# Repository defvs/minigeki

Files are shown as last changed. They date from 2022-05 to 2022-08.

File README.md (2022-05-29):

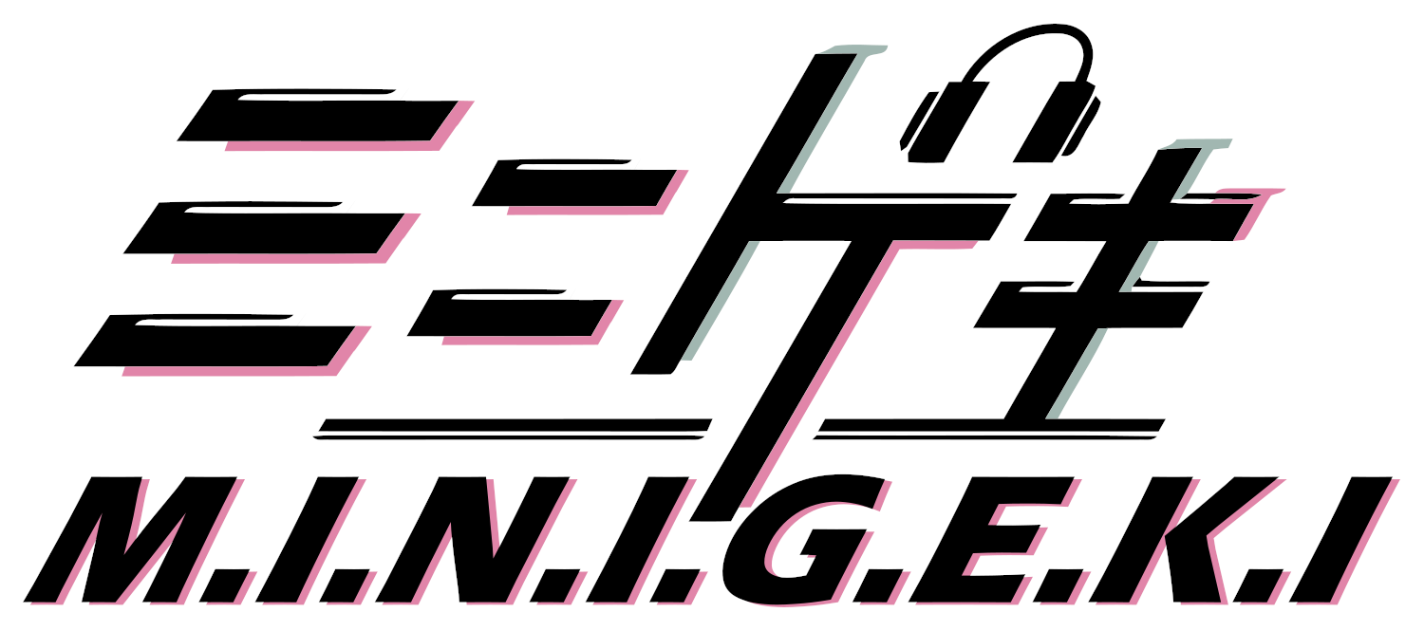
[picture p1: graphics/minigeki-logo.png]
Minigeki Logo

# M.I.N.I.G.E.K.I : a portable ONGEKI controller

A portable implementation of an ONGEKI controller, with all necessary buttons, two macros, RGB LED support, USB-C.

## Hardware setup

- Raspberry RP2040 microcontroller
- 10 hotswappable Cherry MX switches (2x Start, 2x Wall, 2x R+G+B), 2 Macro switches
- 10 RGB daisy-chained WS2812-compatible LEDs (Under every switch except Start, and two under the board)
- USB Type-C connector for both data and power. 

## Software capabilities

- HID Gamepad mode or HID Mouse/Keyboard mode
    - Switchable on boot
- Software addressable RGB via HID
- Auto-rollback to static RGB LEDs if no HID is detected
    - LED can be disabled on boot
- High polling rate
- Switch debouncing
- 8-bit slider position

## Based on / sources

- This project's code is based on SpeedyPotato's [Pico-Game-Controller](https://github.com/speedypotato/Pico-Game-Controller)
    - It also includes sources from Raspberry Pi's [pico-examples](https://github.com/raspberrypi/pico-examples)
- This project's PCB is based on Raspberry Pi's [RP2040-Minimal design](https://datasheets.raspberrypi.com/rp2040/Minimal-KiCAD.zip)

## License and Open Source licensing

minigeki is under GPLv3 in compliance with the usage of existing GPLv3 code. License information can be found in the LICENSE file.

A list of open source components and their licenses can be found in the LICENSING file.

## Extra credit and thank you

- CrazyRedMachine
- megumi_akasaka
- SpeedyPotato

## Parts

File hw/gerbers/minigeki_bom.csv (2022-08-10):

Item | Qty | Reference(s) | Value | LibPart | Footprint | Datasheet | Description | Load Capacitance | MPN | Package
1 | 2 | C1, C4 | 10u | Device:C | Capacitor_SMD:C_0805_2012Metric | ~ |  |  |  | 0805
2 | 2 | C2, C3 | 27p | Device:C | Capacitor_SMD:C_0402_1005Metric | ~ |  |  |  | 0402
3 | 20 | C5, C6, C7, C9, C11, C12, C13, C14, C15, C16, C17, C18, C19, C20, C21, C22, C23, C24, C25, C26 | 100n | Device:C | Capacitor_SMD:C_0402_1005Metric | ~ |  |  |  | 0402
4 | 2 | C8, C10 | 1u | Device:C | Capacitor_SMD:C_0402_1005Metric | ~ |  |  |  | 0402
5 | 10 | D1, D2, D3, D4, D5, D6, D7, D8, D9, D10 | SK6812MINI | LED:SK6812MINI | LED_SMD:LED_SK6812MINI_PLCC4_3.5x3.5mm_P1.75mm | https://cdn-shop.adafruit.com/product-files/2686/SK6812MINI_REV.01-1-2.pdf | SK6812MINI |  | SK6812MINI | PLCC4_3.5x3.5mm_P1.75mm
6 | 1 | J1 | USB_C_Receptacle_USB2.0 | Connector:USB_C_Receptacle_USB2.0 | Connector_USB:USB_C_Receptacle_XKB_U262-16XN-4BVC11 | https://www.usb.org/sites/default/files/documents/usb_type-c.zip | U262-161N-4BVC11 |  | U262-161N-4BVC11 | U262-161N-4BVC11
8 | 2 | R1, R5 | 1k | Device:R | Capacitor_SMD:C_0402_1005Metric | ~ |  |  |  | 0402
9 | 1 | R2 | DNF | Device:R | Capacitor_SMD:C_0402_1005Metric | ~ |  |  |  | 0402
10 | 2 | R3, R4 | 27 | Device:R | Capacitor_SMD:C_0402_1005Metric | ~ |  |  |  | 0402
11 | 2 | R6, R7 | 5.11k | Device:R | Resistor_SMD:R_0402_1005Metric | ~ |  |  |  | 0402
12 | 1 | RV1 | PTA4543-2015DPB103 | Device:R_Potentiometer | PTAXX33:PTAXX43 | ~ | PTA4543-2015DPB103 |  | PTA4543-2015DPB103
23 | 1 | U1 | NCP1117-3.3_SOT223 | Regulator_Linear:NCP1117-3.3_SOT223 | Package_TO_SOT_SMD:SOT-223-3_TabPin2 | http://www.onsemi.com/pub_link/Collateral/NCP1117-D.PDF | NCP1117ST33T3G |  | NCP1117ST33T3G | SOT223-3
24 | 1 | U2 | W25Q128JVS | Memory_Flash:W25Q128JVS | Package_SO:SOIC-8_5.23x5.23mm_P1.27mm | http://www.winbond.com/resource-files/w25q128jv_dtr%20revc%2003272018%20plus.pdf | W25Q128JVS |  | W25Q128JVS | SOIC-8_5.23x5.23mm_P1.27mm
25 | 1 | U3 | RP2040 | MCU_RaspberryPi_RP2040:RP2040 | RP2040_minimal:RP2040-QFN-56 |  | RP2040 |  | RP2040 | QFN-56
26 | 1 | Y1 | Q22FA23V0041800 | Device:Crystal_GND24 | Crystal:Crystal_SMD_3225-4Pin_3.2x2.5mm | https://datasheet.lcsc.com/lcsc/1811051112_Seiko-Epson-Q22FA23V0041800_C91749.pdf | Q22FA23V0041800 | 18p | Q22FA23V0041800 | MD_3225-4Pin_3.2x2.5mm

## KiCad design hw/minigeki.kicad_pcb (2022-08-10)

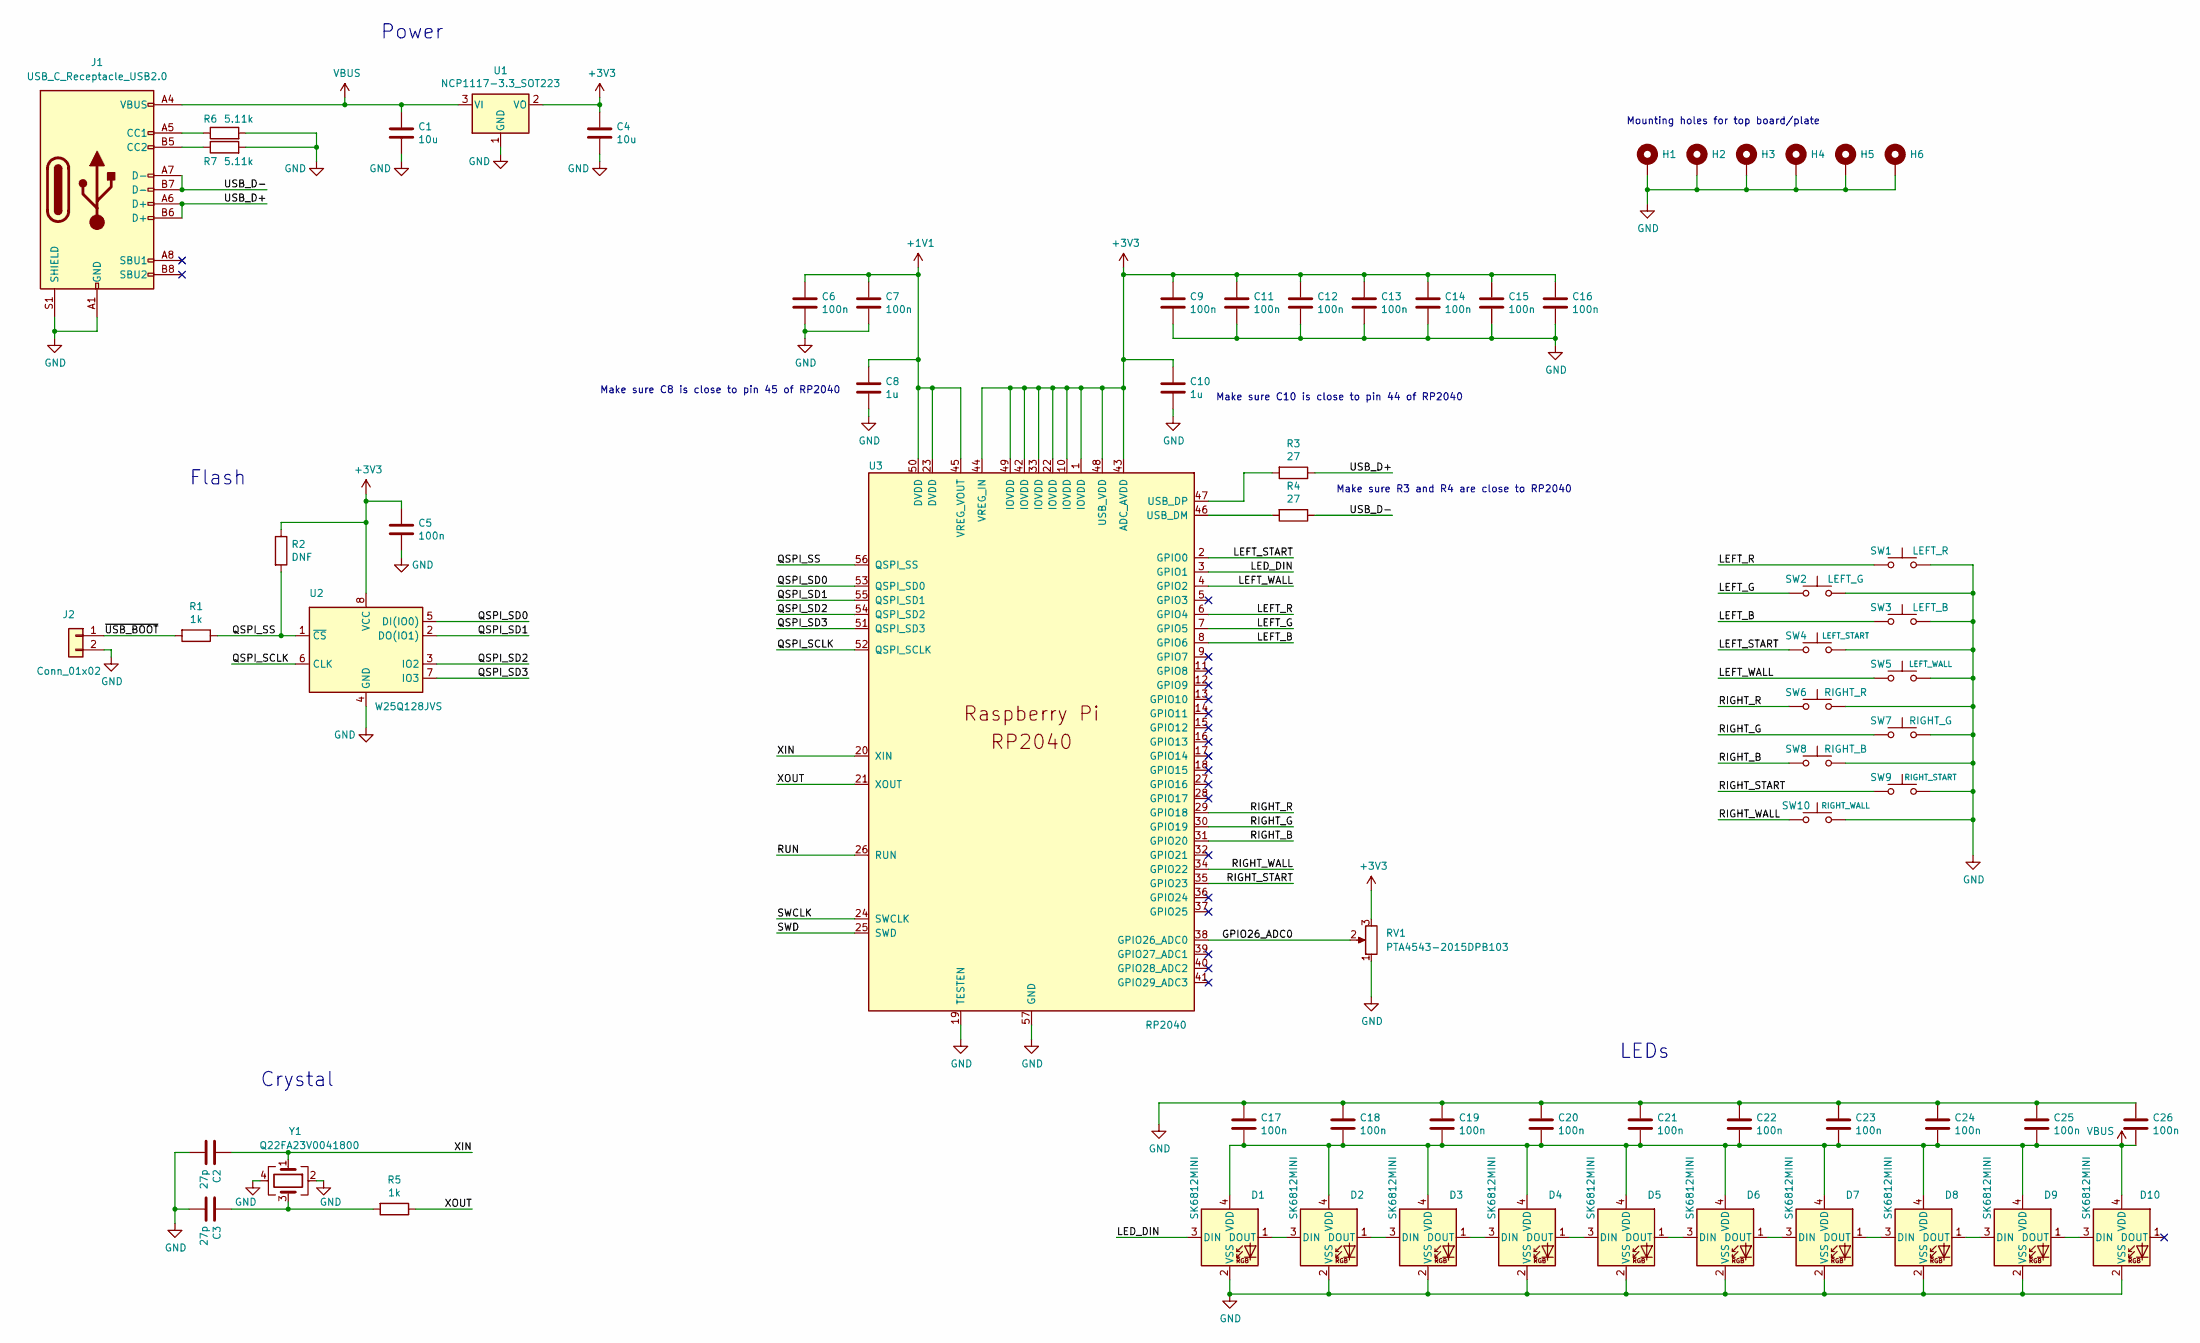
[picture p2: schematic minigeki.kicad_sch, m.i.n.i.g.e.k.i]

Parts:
C1, C4: 10u; C_0805_2012Metric
C2, C3: 27p; C_0402_1005Metric
C5, C6, C7, C9, C11, C12, C13, C14, C15, C16, C17, C18, C19, C20, C21, C22, C23, C24, C25, C26: 100n; C_0402_1005Metric
C8, C10: 1u; C_0402_1005Metric
D1, D2, D3, D4, D5, D6, D7, D8, D9, D10: SK6812MINI; LED_SK6812MINI_PLCC4_3.5x3.5mm_P1.75mm; MPN SK6812MINI
H1, H2, H3, H4, H5, H6: MountingHole_Pad; MountingHole_2.2mm_M2_Pad_TopOnly
J1: USB_C_Receptacle_USB2.0; USB_C_Receptacle_XKB_U262-16XN-4BVC11; MPN U262-161N-4BVC11
J2: Conn_01x02; PinHeader_1x02_P2.54mm_Vertical
R1, R5: 1k; C_0402_1005Metric
R2: DNF; C_0402_1005Metric
R3, R4: 27; C_0402_1005Metric
R6, R7: 5.11k; R_0402_1005Metric
RV1: PTA4543-2015DPB103; PTAXX43; MPN PTA4543-2015DPB103
SW1: LEFT_R; SW_Hotswap_Kailh_MX_1.00u
SW2: LEFT_G; SW_Hotswap_Kailh_MX_1.00u
SW3: LEFT_B; SW_Hotswap_Kailh_MX_1.00u
SW4: LEFT_START; SW_Hotswap_Kailh_MX_1.00u
SW5: LEFT_WALL; SW_Hotswap_Kailh_MX_2.00u
SW6: RIGHT_R; SW_Hotswap_Kailh_MX_1.00u
SW7: RIGHT_G; SW_Hotswap_Kailh_MX_1.00u
SW8: RIGHT_B; SW_Hotswap_Kailh_MX_1.00u
SW9: RIGHT_START; SW_Hotswap_Kailh_MX_1.00u
SW10: RIGHT_WALL; SW_Hotswap_Kailh_MX_2.00u
U1: NCP1117-3.3_SOT223; SOT-223-3_TabPin2; MPN NCP1117ST33T3G
U2: W25Q128JVS; SOIC-8_5.23x5.23mm_P1.27mm; MPN W25Q128JVS
U3: RP2040; RP2040-QFN-56; MPN RP2040
Y1: Q22FA23V0041800; Crystal_SMD_3225-4Pin_3.2x2.5mm; MPN Q22FA23V0041800

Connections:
+1V1: C6.1, C7.1, C8.1, U3.23 (DVDD), U3.45 (VREG_VOUT), U3.50 (DVDD)
+3V3: C4.1, C5.1, C9.1, C10.1, C11.1, C12.1, C13.1, C14.1, C15.1, C16.1, R2.1, RV1.3, U1.2 (VO), U2.8 (VCC), U3.1 (IOVDD), U3.10 (IOVDD), U3.22 (IOVDD), U3.33 (IOVDD), U3.42 (IOVDD), U3.43 (ADC_AVDD), U3.44 (VREG_IN), U3.48 (USB_VDD), U3.49 (IOVDD)
/GPIO26_ADC0: RV1.2, U3.38 (GPIO26_ADC0)
/LED_DIN: D1.3 (DIN), U3.3 (GPIO1)
/LEFT_B: SW3.1, U3.8 (GPIO6)
/LEFT_G: SW2.1, U3.7 (GPIO5)
/LEFT_R: SW1.1, U3.6 (GPIO4)
/LEFT_START: SW4.1, U3.2 (GPIO0)
/LEFT_WALL: SW5.1, U3.4 (GPIO2)
/QSPI_SCLK: U2.6 (CLK), U3.52 (QSPI_SCLK)
/QSPI_SD0: U2.5 (DI(IO0)), U3.53 (QSPI_SD0)
/QSPI_SD1: U2.2 (DO(IO1)), U3.55 (QSPI_SD1)
/QSPI_SD2: U2.3 (IO2), U3.54 (QSPI_SD2)
/QSPI_SD3: U2.7 (IO3), U3.51 (QSPI_SD3)
/QSPI_SS: R1.1, R2.2, U2.1 (~CS), U3.56 (QSPI_SS)
/RIGHT_B: SW8.1, U3.31 (GPIO20)
/RIGHT_G: SW7.1, U3.30 (GPIO19)
/RIGHT_R: SW6.1, U3.29 (GPIO18)
/RIGHT_START: SW9.1, U3.35 (GPIO23)
/RIGHT_WALL: SW10.1, U3.34 (GPIO22)
/RUN: U3.26 (RUN)
/SWCLK: U3.24 (SWCLK)
/SWD: U3.25 (SWD)
/USB_D+: J1.A6 (D+), J1.B6 (D+), R3.1
/USB_D-: J1.A7 (D-), J1.B7 (D-), R4.1
/XIN: C2.1, U3.20 (XIN), Y1.1
/XOUT: R5.1, U3.21 (XOUT)
/~USB_BOOT: J2.1, R1.2
GND: C1.2, C2.2, C3.2, C4.2, C5.2, C6.2, C7.2, C8.2, C9.2, C10.2, C11.2, C12.2, C13.2, C14.2, C15.2, C16.2, C17.1, C18.1, C19.1, C20.1, C21.1, C22.1, C23.1, C24.1, C25.1, C26.1, D1.2 (VSS), D2.2 (VSS), D3.2 (VSS), D4.2 (VSS), D5.2 (VSS), D6.2 (VSS), D7.2 (VSS), D8.2 (VSS), D9.2 (VSS), D10.2 (VSS), H1.1, H2.1, H3.1, H4.1, H5.1, H6.1, J1.A1 (GND), J1.A12 (GND), J1.B1 (GND), J1.B12 (GND), J1.S1 (SHIELD), J2.2, R6.2, R7.2, RV1.1, SW1.2, SW2.2, SW3.2, SW4.2, SW5.2, SW6.2, SW7.2, SW8.2, SW9.2, SW10.2, U1.1 (GND), U2.4 (GND), U3.19 (TESTEN), U3.57 (GND), Y1.2, Y1.4
unnamed: C3.1, R5.2, Y1.3
unnamed: D1.1 (DOUT), D2.3 (DIN)
unnamed: D2.1 (DOUT), D3.3 (DIN)
unnamed: D3.1 (DOUT), D4.3 (DIN)
unnamed: D4.1 (DOUT), D5.3 (DIN)
unnamed: D5.1 (DOUT), D6.3 (DIN)
unnamed: D6.1 (DOUT), D7.3 (DIN)
unnamed: D7.1 (DOUT), D8.3 (DIN)
unnamed: D8.1 (DOUT), D9.3 (DIN)
unnamed: D9.1 (DOUT), D10.3 (DIN)
unnamed: J1.A5 (CC1), R6.1
unnamed: J1.B5 (CC2), R7.1
unnamed: R3.2, U3.47 (USB_DP)
unnamed: R4.2, U3.46 (USB_DM)
VBUS: C1.1, C17.2, C18.2, C19.2, C20.2, C21.2, C22.2, C23.2, C24.2, C25.2, C26.2, D1.4 (VDD), D2.4 (VDD), D3.4 (VDD), D4.4 (VDD), D5.4 (VDD), D6.4 (VDD), D7.4 (VDD), D8.4 (VDD), D9.4 (VDD), D10.4 (VDD), J1.A4 (VBUS), J1.A9 (VBUS), J1.B4 (VBUS), J1.B9 (VBUS), U1.3 (VI)

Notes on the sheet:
Mounting holes for top board/plate
LEDs
Make sure C10 is close to pin 44 of RP2040
Power
Crystal
Make sure C8 is close to pin 45 of RP2040
Flash
Make sure R3 and R4 are close to RP2040

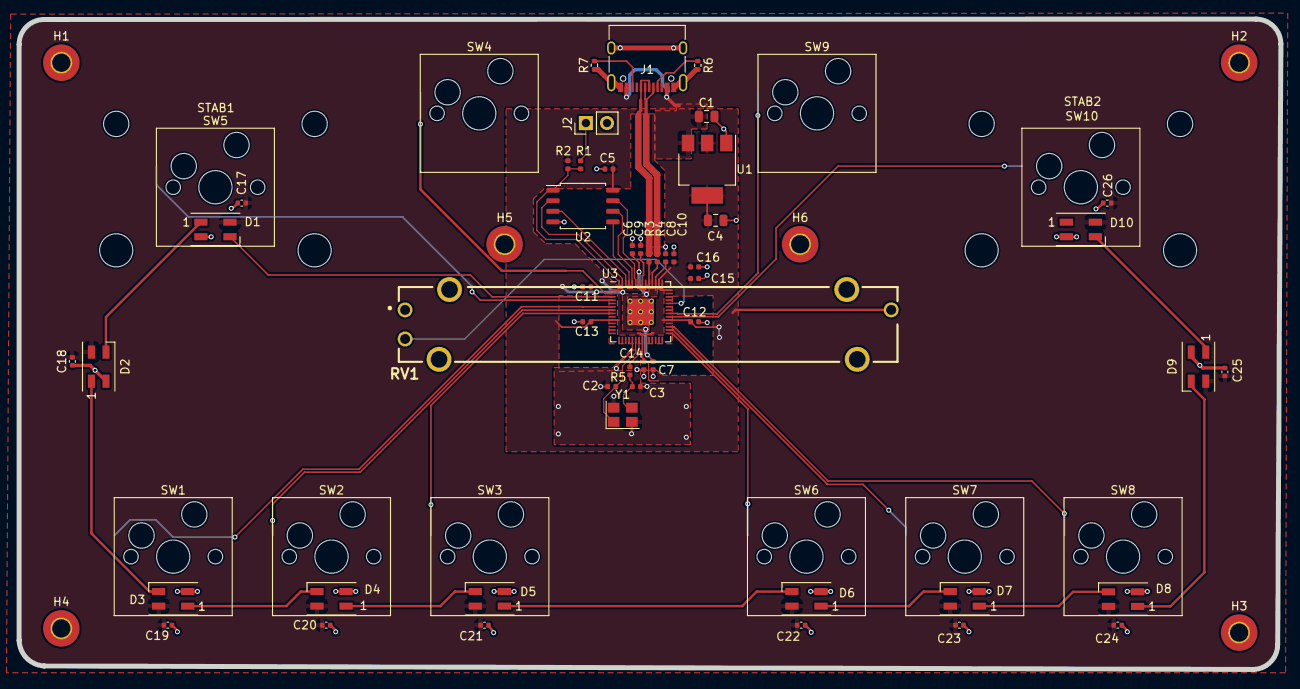
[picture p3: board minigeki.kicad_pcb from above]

Board: 2 copper layers, 151.8 x 78.3 mm, 68 parts (0 on the bottom side), 41 nets.

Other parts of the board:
STAB1, STAB2: Stabilizer_Cherry_MX_2.00u

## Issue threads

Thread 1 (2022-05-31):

hw: Change crystal oscillator with a low-profile one

defvs, 2022-05-31:
Current crystal is bulky.

Closed 2022-07-26.

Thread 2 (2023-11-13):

Pin definitions wrong for currently supplied PCB.

dude22072, 2023-11-13:
Almost thought my LEDs were all duds until I dug through the code and found that `WS2812B_GPIO` was 24 instead of 1. Comparing the `SW_GPIO` array to the kicad files it seems things were moved around at some point but the code wasn't updated.

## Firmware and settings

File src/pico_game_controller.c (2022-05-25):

/*
 * M.I.N.I.G.E.K.I v2
 * @author defvs
 * Adapted from original by SpeedyPotato. Licensed under GPLv3
 *
 * LICENSE CLAUSE - GPLv3
 * The software included in this product contains copyrighted software that is licensed under the GPLv3.
 * A copy of that license is included in this document on page X.
 * You may obtain the complete Corresponding Source code from us for a period of three years after our
 *      last shipment of this product and/or spare parts therefor.
 * You can obtain the full source code for this project at https://github.com/defvs/minigeki
 */
#define PICO_GAME_CONTROLLER_C

#include <stdio.h>
#include <stdlib.h>

#include "bsp/board.h"
#include "controller_config.h"
#include "encoders.pio.h"
#include "hardware/clocks.h"
#include "hardware/adc.h"
#include "pico/multicore.h"
#include "tusb.h"
#include "usb_descriptors.h"
#include "ws2812.pio.h"

PIO pio_1;
uint16_t slider_val;
uint16_t prev_slider_val;

bool prev_sw_val[SW_GPIO_SIZE];
uint64_t sw_timestamp[SW_GPIO_SIZE];

bool kbm_report;

uint64_t reactive_timeout_timestamp;

void (*loop_mode)();

bool joy_mode_check = true;

union {
	RGB_t rgb[WS2812B_LEDS];
	uint8_t raw[WS2812B_LEDS * 3];
} lights_report;

RGB_t rgb_reactive_current[WS2812B_LEDS];

/**
 * WS2812B RGB Assignment
 * @param pixel_grb The pixel color to set
 **/
static inline void put_pixel(uint32_t pixel_grb) {
	pio_sm_put_blocking(pio1, 0, pixel_grb << 8u);
}

/**
 * WS2812B RGB Format Helper
 **/
static inline uint32_t urgb_u32(uint8_t r, uint8_t g, uint8_t b) {
	return ((uint32_t) (r) << 8) | ((uint32_t) (g) << 16) | (uint32_t) (b);
}

static inline uint32_t urgb(RGB_t pixel) {
    return urgb_u32(pixel.r, pixel.g, pixel.b);
}

/**
 * WS2812B Lighting
 * @param counter Current number of WS2812B cycles
 **/
void ws2812b_update() {
    for (int i = 0; i < WS2812B_LEDS; ++i) {
        put_pixel(urgb(rgb_reactive_current[i]));
    }
}

/**
 * HID/Reactive Lights
 **/
void update_lights() {
	if (time_us_64() - reactive_timeout_timestamp >= REACTIVE_TIMEOUT_MAX) {
		// Reactive mode: we set the LEDs ourselves.
		// TODO: LED react to button press.
		RGB_t value;
		for (int i = 0; i < WS2812B_LEDS; ++i) {
			value = RGB_REACTIVE_VALUES[i];
			if (value.r == 0 && value.g == 0 && value.b <= 1) { // Special mode
				uint8_t calcValue;
				if (value.b == 0)
					calcValue = slider_val;
				else
					calcValue = (1<<7) - slider_val;
				rgb_reactive_current[i].r = rgb_reactive_current[i].g = rgb_reactive_current[i].b = calcValue;
			} else rgb_reactive_current[i] = value;
		}
	} else {
		// HID mode: copy RGB values from received report
		for (int i = 0; i < WS2812B_LEDS; i++) rgb_reactive_current[i] = lights_report.rgb[i];
	}
}

struct report {
	uint16_t buttons;
	uint8_t joy0;
	uint8_t joy1;
} report;

/**
 * Gamepad Mode
 **/
void joy_mode() {
	if (tud_hid_ready()) {
		uint16_t translate_buttons = 0;
		for (int i = SW_GPIO_SIZE - 1; i >= 0; i--) {
			if (!gpio_get(SW_GPIO[i]) &&
				time_us_64() - sw_timestamp[i] >= SW_DEBOUNCE_TIME_US) {
				translate_buttons =
						(translate_buttons << 1) | (!gpio_get(SW_GPIO[i]) ? 1 : 0);
			} else {
				translate_buttons <<= 1;
			}
		}
		report.buttons = translate_buttons;

		report.joy0 = slider_val;
		report.joy1 = 0;

		tud_hid_n_report(0x00, REPORT_ID_JOYSTICK, &report, sizeof(report));
	}
}

/**
 * Keyboard Mode
 **/
void key_mode() {
	if (tud_hid_ready()) {  // Wait for ready, updating mouse too fast hampers
		// movement
		/*------------- Keyboard -------------*/
		uint8_t nkro_report[32] = {0};
		for (int i = 0; i < SW_GPIO_SIZE; i++) {
			if (!gpio_get(SW_GPIO[i]) &&
				time_us_64() - sw_timestamp[i] >= SW_DEBOUNCE_TIME_US) {
				uint8_t bit = SW_KEYCODE[i] % 8;
				uint8_t byte = (SW_KEYCODE[i] / 8) + 1;
				if (SW_KEYCODE[i] >= 240 && SW_KEYCODE[i] <= 247) {
					nkro_report[0] |= (1 << bit);
				} else if (byte > 0 && byte <= 31) {
					nkro_report[byte] |= (1 << bit);
				}
			}
		}

		/*------------- Mouse -------------*/
		// find the delta between previous and current slider_val
		uint16_t delta = (slider_val - prev_slider_val);
		prev_slider_val = slider_val;

		if (kbm_report) {
			tud_hid_n_report(0x00, REPORT_ID_KEYBOARD, &nkro_report,
							 sizeof(nkro_report));
		} else {
			tud_hid_mouse_report(REPORT_ID_MOUSE, 0x00, delta * MOUSE_SENS,0, 0, 0);
		}
		// Alternate reports
		kbm_report = !kbm_report;
	}
}

/**
 * Update Input States
 * Note: Switches are pull up, negate value
 **/
void update_inputs() {
	for (int i = 0; i < SW_GPIO_SIZE; i++) {
		// If switch gets pressed, record timestamp
		if (prev_sw_val[i] == false && !gpio_get(SW_GPIO[i]) == true) {
			sw_timestamp[i] = time_us_64();
		}
		prev_sw_val[i] = !gpio_get(SW_GPIO[i]);
	}
	slider_val = adc_read();
}

/**
 * Second Core Runnable
 **/
void core1_entry() {
	while (1) {
		ws2812b_update();
		sleep_ms(5);
	}
}

/**
 * Initialize Board Pins
 **/
void init() {
	reactive_timeout_timestamp = time_us_64();

	// Set up WS2812B
	pio_1 = pio1;
	uint offset2 = pio_add_program(pio_1, &ws2812_program);
	ws2812_program_init(pio_1, 0, offset2, WS2812B_GPIO, 800000,false);

	// Setup Button GPIO
	for (int i = 0; i < SW_GPIO_SIZE; i++) {
		prev_sw_val[i] = false;
		sw_timestamp[i] = 0;
		gpio_init(SW_GPIO[i]);
		gpio_set_function(SW_GPIO[i], GPIO_FUNC_SIO);
		gpio_set_dir(SW_GPIO[i], GPIO_IN);
		gpio_pull_up(SW_GPIO[i]);
	}

	// Setup ADC
	adc_init();
	adc_gpio_init(ADC_PIN);
	adc_select_input(ADC_PIN - 26);

	// Set listener bools
	kbm_report = false;

	// Joy/KB Mode Switching
	if (!gpio_get(SW_GPIO[0])) {
		loop_mode = &key_mode;
		joy_mode_check = false;
	} else {
		loop_mode = &joy_mode;
		joy_mode_check = true;
	}

	// Disable RGB
	if (gpio_get(SW_GPIO[8])) {
		multicore_launch_core1(core1_entry);
	} else {
        for (int i = 0; i < WS2812B_LEDS; ++i) {
            put_pixel(urgb_u32(0, 0, 0));
        }
	}
}

/**
 * Main Loop Function
 **/
int main(void) {
	board_init();
	init();
	tusb_init();

	while (1) {
		tud_task();  // tinyusb device task
		update_inputs();
		loop_mode();
		update_lights();
	}
}

// Invoked when received GET_REPORT control request
// Application must fill buffer report's content and return its length.
// Return zero will cause the stack to STALL request
uint16_t tud_hid_get_report_cb(uint8_t itf, uint8_t report_id,
							   hid_report_type_t report_type, uint8_t *buffer,
							   uint16_t reqlen) {
	// TODO not Implemented
	(void) itf;
	(void) report_id;
	(void) report_type;
	(void) buffer;
	(void) reqlen;

	return 0;
}

// Invoked when received SET_REPORT control request or
// received data on OUT endpoint ( Report ID = 0, Type = 0 )
void tud_hid_set_report_cb(uint8_t itf, uint8_t report_id,
						   hid_report_type_t report_type, uint8_t const *buffer,
						   uint16_t bufsize) {
	(void) itf;
	if (report_id == 2 && report_type == HID_REPORT_TYPE_OUTPUT &&
		bufsize >= sizeof(lights_report))  // light data
	{
		for (size_t i = 0; i < sizeof(lights_report); i++) {
			lights_report.raw[i] = buffer[i];
		}
		reactive_timeout_timestamp = time_us_64();
	}
}

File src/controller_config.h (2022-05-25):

/*
 * M.I.N.I.G.E.K.I v2
 * @author defvs
 * Adapted from original by SpeedyPotato. Licensed under GPLv3
 *
 * LICENSE CLAUSE - GPLv3
 * The software included in this product contains copyrighted software that is licensed under the GPLv3.
 * A copy of that license is included in this document on page X.
 * You may obtain the complete Corresponding Source code from us for a period of three years after our
 *      last shipment of this product and/or spare parts therefor.
 * You can obtain the full source code for this project at https://github.com/defvs/minigeki
 */

#ifndef CONTROLLER_CONFIG_H
#define CONTROLLER_CONFIG_H

#define SW_GPIO_SIZE 12               // Number of switches
#define MOUSE_SENS 1                  // Mouse sensitivity multiplier
#define SW_DEBOUNCE_TIME_US 4000      // Switch debounce delay in us
#define REACTIVE_TIMEOUT_MAX 1000000  // HID to reactive timeout in us
#define WS2812B_LEDS 10           // Number of WS2812B LEDs
#define ADC_PIN 26

#ifdef PICO_GAME_CONTROLLER_C

typedef struct {
	uint8_t r, g, b;
} RGB_t;

// MODIFY KEYBINDS HERE, MAKE SURE LENGTHS MATCH SW_GPIO_SIZE
const uint8_t SW_KEYCODE[] = {HID_KEY_D, HID_KEY_F, HID_KEY_J, HID_KEY_K,
                              HID_KEY_C, HID_KEY_M, HID_KEY_A, HID_KEY_B,
                              HID_KEY_1, HID_KEY_E, HID_KEY_G};
const uint8_t SW_GPIO[] = {
    4, 5, 6, 12, 13, 14, 18, 19, 20, 27, 28, 29,
};
const uint8_t WS2812B_GPIO = 24;

// Value of 0, 0, X will be reactive on the slider position. 0,0,0 for left, 0,0,1 for right section
const RGB_t RGB_REACTIVE_VALUES[WS2812B_LEDS] = {
		{201, 130, 217}, // LEFT_WALL
		{0,0,0}, // Left programmable
		{255, 84, 84}, // LEFT_R
		{107, 255, 84}, // LEFT_G
		{84, 127, 255}, // LEFT_B
		{255, 84, 84}, // RIGHT_R
		{107, 255, 84}, // RIGHT_G
		{84, 127, 255}, // RIGHT_B
		{0,0,1}, // Right programmable
		{201, 130, 217}, // RIGHT_WALL
};

#endif

extern bool joy_mode_check;

#endif

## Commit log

2022-05-18 Buttons to HID Gamepad implementation
2022-05-20 Add v2 hardware files
    [RP2040_minimal.kicad_pcb, RP2040_minimal.kicad_sch, RP2040_minimal.sch]
2022-05-24 hw: Add linear potentiometer
    [RP2040_minimal.kicad_sch]
2022-05-24 hw: rename kicad project
    [minigeki.kicad_pcb, minigeki.kicad_sch, minigeki.sch]
2022-05-24 hw: finish main routing
    [minigeki.kicad_pcb, minigeki.kicad_sch]
2022-05-24 hw: final routing pass
    [minigeki.kicad_pcb]
2022-05-24 hw: update schematic to reflect PCB changes
    [minigeki.kicad_sch]
2022-05-25 sw: fix LED code
    [pico_game_controller.c]
2022-05-28 hw: add mounting holes
    [minigeki.kicad_pcb]
2022-05-28 hw: v2 gerbers export
    [minigeki-B_Cu.gbr, minigeki-B_Mask.gbr, minigeki-B_Paste.gbr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]
2022-05-28 hw: fix GND copper area not filling everything
    [minigeki-B_Cu.gbr, minigeki-B_Mask.gbr, minigeki-B_Paste.gbr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]
2022-06-08 hw: add mounting holes, flip components to top of the board
    [minigeki.kicad_pcb, minigeki.kicad_sch]
2022-06-09 hw: final PCB for v3.0
    [minigeki.kicad_pcb, minigeki.kicad_sch]
2022-06-09 hw: export gerber
    [minigeki-B_Cu.gbr, minigeki-B_Mask.gbr, minigeki-B_Paste.gbr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]
2022-06-12 Clean up BOM
    [minigeki.csv]
2022-08-10 hw: final prototype export
    [minigeki.csv, minigeki.kicad_pcb, minigeki.kicad_sch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]
